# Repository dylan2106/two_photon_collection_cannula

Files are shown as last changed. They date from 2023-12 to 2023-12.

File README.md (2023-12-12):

# two photon collection cannula
The following files describe the conical cannula used to improve collection efficiency in the following work
https://www.biorxiv.org/content/10.1101/2023.08.17.553594v1

## file descriptions ##

reflector_test_with_excitation.zos - This file is for loading in Zemax Optic studio to simulate the collection grain. It has the following dependency
https://community.zemax.com/code-exchange-10/dll-source-non-sequential-fan-and-ring-sources-1437



conic_reflector_5.ipt - This file is the inventor part for the conical cannula.


machining_conical_steps.docx - This file describes the machining steps for manufacturing the cannula on a lathe.

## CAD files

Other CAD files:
conic_reflector_5.ipt

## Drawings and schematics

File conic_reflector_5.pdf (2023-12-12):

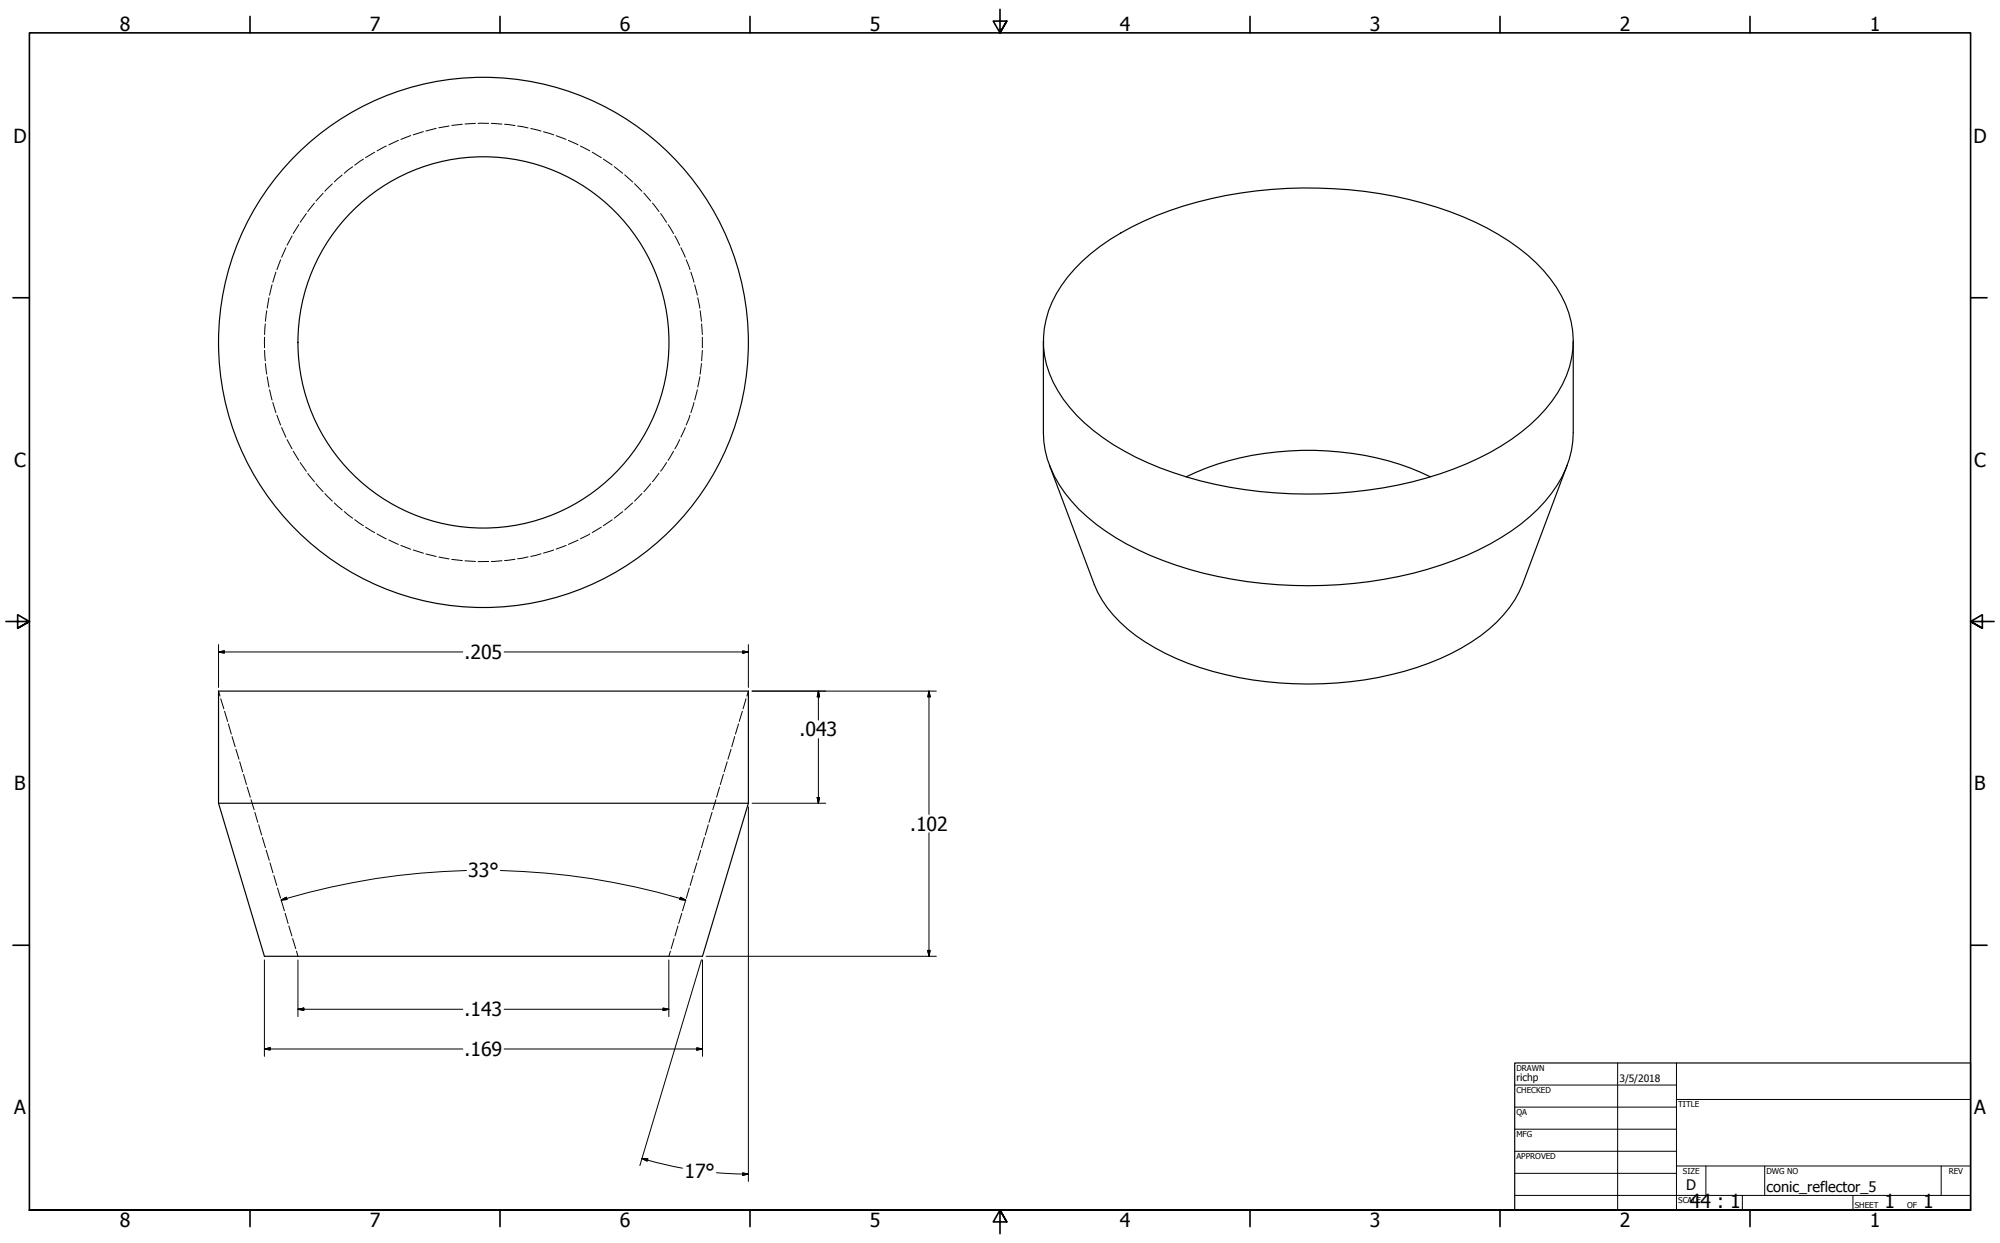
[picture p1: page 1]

DRAWN richp | 3/5/2018

CHECKED

MFG

APPROVED

SIZE D | DWG NO conic_reflector_5 | REV

44 : 1 SCALE | | SHEET 1 OF 1

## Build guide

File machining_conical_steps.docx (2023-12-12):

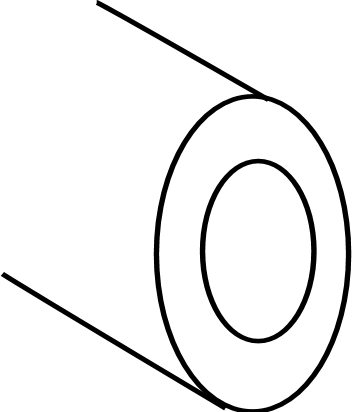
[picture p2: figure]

1) a) Square off stock with cut off tool

b) cut ridge to the OD with cutoff tool

2) #2centre drill to reach OD mark

3) 29 drill to bottom of hole

4) a) find clearance with boring tool in the hole (end of compound axis

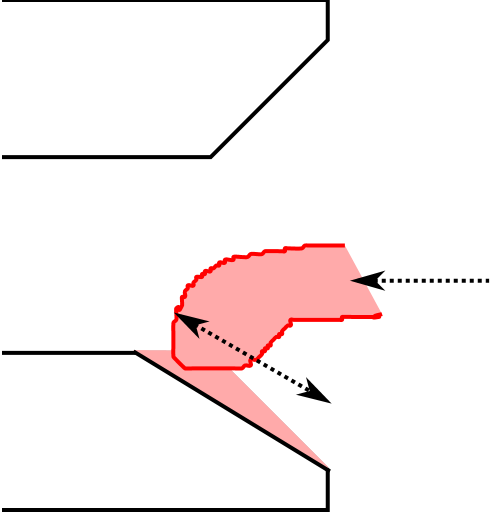
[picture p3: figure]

b) adjust y stage to get close to ID cut

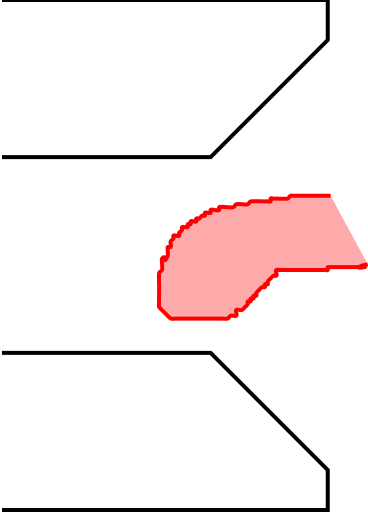
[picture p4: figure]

c) use compound to take passes

d) move to next pass with X stage

c) proceed to OD mark or just before

5) final cut taken at 1250rpm, slow in and out

6) clean off cutting fluid

7) with a slow chuck rotation, use a 3mm diamond polishing pin

Hold like a pen and apply a fair ammount of pressure

Blue> Red > White

8) a) polish with 3mm felt pin, and simachrome paste

b) then with a new clean 3mm felt pin

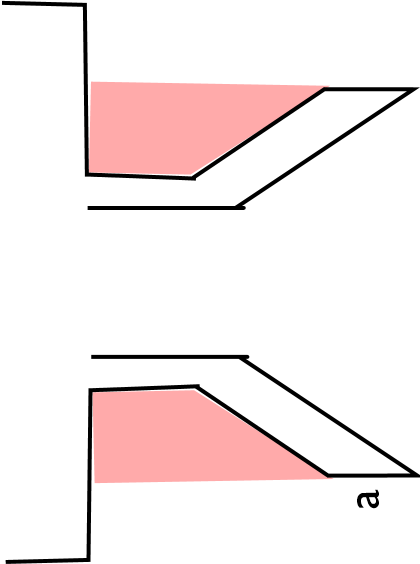
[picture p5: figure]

9) turn OD with triangulr cutter

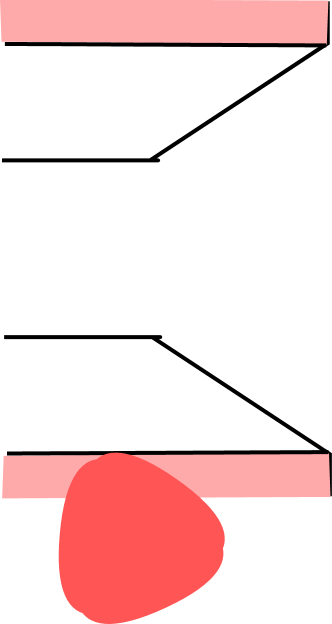
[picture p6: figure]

Take care with sharp edge, take small passes towards end

10) profile outer (use width of a as a guide)

11) take a zero with the cut off tool at the open face

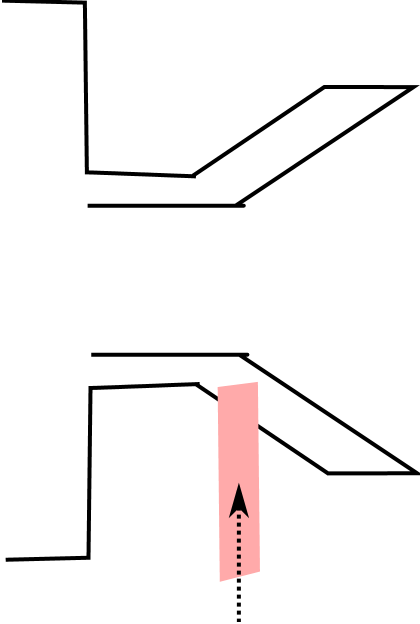
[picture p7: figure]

Cutter should have enough clearance so it is not going

Through a lot of stock on the left hand side

This will give a clean cut off on the internal surface
